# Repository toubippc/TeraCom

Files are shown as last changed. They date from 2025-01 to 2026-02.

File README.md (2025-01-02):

# Firware TeraCom esp32

Version beta : 0.2

## Description

Ce firware charger sur un esp32 permet le controle de températures, de l'éclairage et de la circulation d'air dans un terrarium.

Via un pin/switch on peu le passer en mode station ( hotspot ),de facon a se connecter directement a l'appareil ( il emet son propre signal wifi/ssid ) ou en mode client, en le connectant a son réseaux existant.
Vou devez pour se faire l'initialisé en vous connectant une première fois en mode station.

### 4 sorties relay

- Chauffage / Tapis de sol
- Lumière chauffante ( spot )
- Lumière spéciale ( UV )
- Ventilation / Humidificateur

### Sondes d'entrées

- 1 DHT 11 (température / Humidité )
- 3 Sondes de témperatures DS18B20

D'autre fonction avec de multiple sondes sont a venir ! 
(la liste est trop longue .. )

> [!IMPORTANT]
> Manuel d'utilisation a venir !

## Technique

### Hardware

- Carte : esp32doit-devkit-v1
- Shéma :
- Sondes compatibles :

### Software

Développé avec VSCode

platform = espressif32 \
board = esp32doit-devkit-v1 \
framework = arduino \
lib_deps =

    - ottowinter/ESPAsyncWebServer-esphome@^3.1.0
    - ottowinter/ESPAsyncTCP-esphome@^1.2.3
    - adafruit/Adafruit Unified Sensor@^1.1.14
    - adafruit/DHT sensor library@^1.4.6
    - paulstoffregen/OneWire@^2.3.8
    - milesburton/DallasTemperature@^3.11.0
    - ayushsharma82/AsyncElegantOTA@^2.2.8

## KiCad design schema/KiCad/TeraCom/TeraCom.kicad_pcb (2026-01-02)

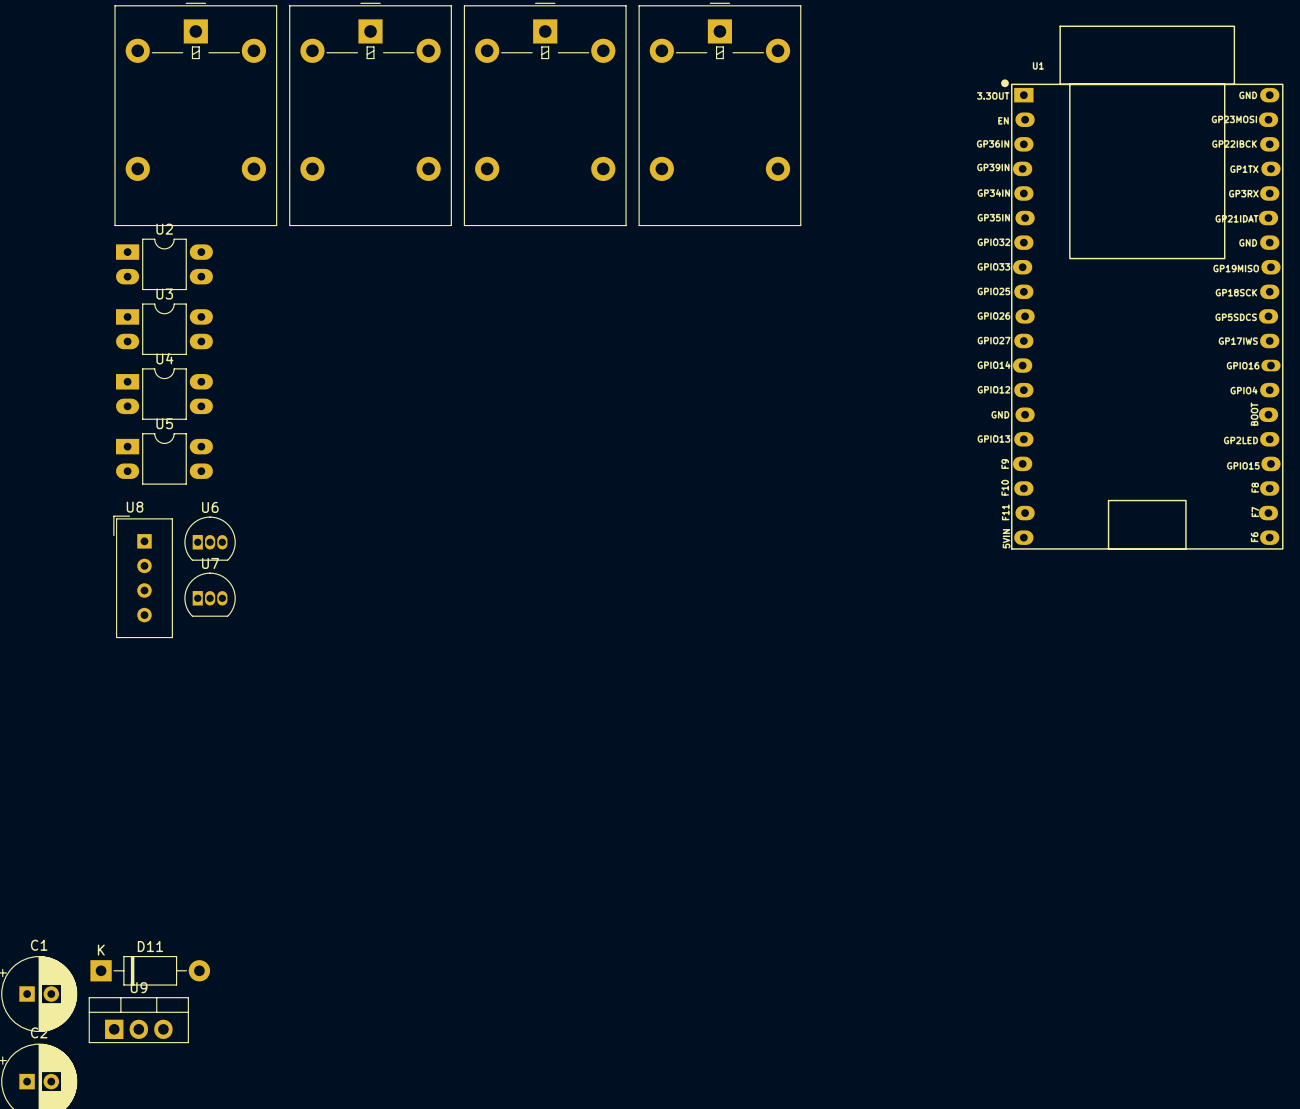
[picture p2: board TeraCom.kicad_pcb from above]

Board: 2 copper layers, 16 parts (0 on the bottom side), 14 nets, no tracks yet.

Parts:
C1, C2: C_Polarized_Small_US; CP_Radial_D7.5mm_P2.50mm
D11: 1N4007; D_DO-41_SOD81_P10.16mm_Horizontal
K1, K2, K3, K5: G5LE-1; Relay_SPDT_Omron-G5LE-1
U1: ESP32-C6-DevKitM-1; Z_ESP32_DevKitC_38pin_socket
U2, U3, U4, U5: PC817; DIP-4_W7.62mm_LongPads
U6, U7: DS18S20; TO-92_Inline
U8: DHT11; Aosong_DHT11_5.5x12.0_P2.54mm
U9: LM7805_TO220; TO-220-3_Vertical

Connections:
+5V: C2.1, U6.3 (V_{DD}), U7.3 (V_{DD}), U8.1 (VDD), U9.3 (VO)
GND_RELAY_CARD: C1.2, C2.2, U2.3, U3.3, U4.3, U5.3, U6.1 (GND), U7.1 (GND), U8.4 (GND), U9.2 (GND)
unnamed: K5.2, U2.4
unnamed: K1.2, U3.4
unnamed: K2.2, U4.4
unnamed: K3.2, U5.4
unnamed: U1.7 (GPIO0), U6.2 (DQ)
unnamed: U1.5 (GPIO4/MTMS), U7.2 (DQ)
unnamed: U1.32 (GPIO32), U8.2 (DATA)
unnamed: C1.1, U9.1 (VI)
POWER_RELAY_CARD: D11.2 (A), K1.5, K2.5, K3.5, K5.5
Relay_INPUT1: U1.28 (GPIO17/U0RXD), U2.2
Relay_INPUT2: U1.22 (GPIO18), U3.2
Relay_INPUT4: U1.29 (GPIO16/U0TXD), U5.2

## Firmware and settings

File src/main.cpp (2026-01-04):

#include "global.h"
#include "wifiSettings.h"
#include "server.h"
#include "wpse324.h"
#include "automation.h"



//UPDATE variabls to blink without delay:
const int led = 2;
unsigned long previousMillis = 0;        // will store last time LED was updated
const long interval = 1000;           // interval at which to blink (milliseconds)
int ledState = LOW;             // ledState used to set the LED


//Variables Server
String esid = "";
String epass = "";
int i = 0;
// Get Wifi mode trigger
int switchWifiMode = 3;

// NTP (time.h)
const char* ntpServer = "pool.ntp.org";
const long  gmtOffset_sec = 0;
const int   daylightOffset_sec = 0;

// SENSORS delay
uint32_t delayMS;

//Function Decalration
void launchWeb(void);
void setupAP(void);

void setup()
{

  Serial.begin(115200); //Initialising if(DEBUG)Serial Monitor
  Serial.println();
  Serial.println("Disconnecting current wifi connection");
  WiFi.disconnect();
  Serial.println("System Initializing ... ");

  pinMode(pinRelay0, OUTPUT);
  pinMode(pinRelay1, OUTPUT);
  pinMode(pinRelay2, OUTPUT);
  pinMode(pinRelay3, OUTPUT);
  pinMode(pinLedWifiAP, OUTPUT);
  pinMode(pinLedWifiSTA, OUTPUT);
  pinMode(pinTriggerAP, INPUT);

  //pinMode(analogIn1, INPUT);
  //pinMode(analogIn2, INPUT);
  //pinMode(analogIn3, INPUT);
  //pinMode(analogIn4, INPUT);

  digitalWrite(pinRelay0, OFF);
  digitalWrite(pinRelay1, OFF);
  digitalWrite(pinRelay2, OFF);
  digitalWrite(pinRelay3, OFF);
  digitalWrite(pinLedWifiAP, LOW);
  digitalWrite(pinLedWifiSTA, LOW);
  //digitalWrite(analogIn1, LOW);
  //digitalWrite(analogIn2, LOW);

  
  // configure LED PWM functionalitites
  ledcSetup(ledChannel, freq, resolution);
  
  // attach the channel to the GPIO to be controlled
  ledcAttachPin(output, ledChannel);
  
  // configure PWM frequency
  ledcWrite(ledChannel, sliderValue.toInt());

  //Initialasing EEPROM
  EEPROM.begin(512); 
  delay(10);
  

  //---------------------------------------- Read eeprom for ssid and pass
  Serial.println("Reading EEPROM ssid");
  for (int i = 0; i < 32; ++i)
  {
    esid += char(EEPROM.read(i));
  }
  Serial.println();
  Serial.print("SSID: ");
  Serial.println(esid);
  Serial.println("Reading EEPROM pass");

  for (int i = 32; i < 96; ++i)
  {
    epass += char(EEPROM.read(i));
  }
  Serial.print("PASS: ");
  Serial.println(epass);

  // Configure WiFi
  WiFi.mode(WIFI_STA);
  WiFi.config(INADDR_NONE, INADDR_NONE, INADDR_NONE, INADDR_NONE);
  WiFi.setHostname(hostname.c_str()); //define hostname
  WiFi.disconnect();
  delay(100);


  // END initialization, start loop
  Serial.println();
  Serial.println("Startup : ");
  Serial.println(hostname.c_str());
  
  // SENSORS
  
   dht.begin();
   wpse324init();
  Serial.println(F("DHTxx Unified Sensor Example"));
  // Print temperature sensor details.
  sensor_t sensor;
  dht.temperature().getSensor(&sensor);
  Serial.println(F("------------------------------------"));
  Serial.println(F("Temperature Sensor"));
  Serial.print  (F("Sensor Type: ")); Serial.println(sensor.name);
  Serial.print  (F("Driver Ver:  ")); Serial.println(sensor.version);
  Serial.print  (F("Unique ID:   ")); Serial.println(sensor.sensor_id);
  Serial.print  (F("Max Value:   ")); Serial.print(sensor.max_value); Serial.println(F("°C"));
  Serial.print  (F("Min Value:   ")); Serial.print(sensor.min_value); Serial.println(F("°C"));
  Serial.print  (F("Resolution:  ")); Serial.print(sensor.resolution); Serial.println(F("°C"));
  Serial.println(F("------------------------------------"));
  // Print humidity sensor details.
  dht.humidity().getSensor(&sensor);
  Serial.println(F("Humidity Sensor"));
  Serial.print  (F("Sensor Type: ")); Serial.println(sensor.name);
  Serial.print  (F("Driver Ver:  ")); Serial.println(sensor.version);
  Serial.print  (F("Unique ID:   ")); Serial.println(sensor.sensor_id);
  Serial.print  (F("Max Value:   ")); Serial.print(sensor.max_value); Serial.println(F("%"));
  Serial.print  (F("Min Value:   ")); Serial.print(sensor.min_value); Serial.println(F("%"));
  Serial.print  (F("Resolution:  ")); Serial.print(sensor.resolution); Serial.println(F("%"));
  Serial.println(F("------------------------------------"));
  // Set delay between sensor readings based on sensor details.
  delayMS = sensor.min_delay / 1000;
         
}


void loop() {

 // analog1Value = analogRead(analogIn1);
 // analog2Value = analogRead(analogIn2);
  // analog3Value = analogRead(analogIn3); // DHT11
  // analog4Value = analogRead(analogIn4);

  //String strAnalog1 = "Analogique 34 : "+analog1Value;
  //Serial.printf("Analogique 3 : %d \n",analog3Value);
  //Serial.printf("Analogique 4 : %d \n", analog4Value);

  // Get Wifi mode trigger
  // Pin trigger LOW && connection false
  if (digitalRead(pinTriggerAP) != 1 && switchWifiMode != digitalRead(pinTriggerAP)) {
    Serial.println(" Wifi station initialization ...");
    switchWifiMode = 0;
    setupSTA();
    if (WiFi.status() == WL_CONNECTED)
      {
          // Init and get the time
        configTime(gmtOffset_sec, daylightOffset_sec, ntpServer);
        setTimezone("CET-1CEST,M3.5.0,M10.5.0/3");
        launchWeb();
        // ElegantOTA.loop();
      }
  } 
  else if(digitalRead(pinTriggerAP) == 1 && switchWifiMode != digitalRead(pinTriggerAP)) {
    Serial.println(" Wifi access point initialization ...");
    setupAP();// Setup HotSpot
    switchWifiMode = 1;
  }
  else {
    // When no connection or lost connection
    if(WiFi.status() != WL_CONNECTED && switchWifiMode == 0 ) {
      // when the connection is lost
      if(WiFi.status() == WL_CONNECTION_LOST ) {
        Serial.println(" Lost connection, reconnect .. ");
        WiFi.reconnect();
      }
      // when disconnected from a network
      else if(WiFi.status() == WL_DISCONNECTED) {
        Serial.println(" Disconnected !");
        switchWifiMode = 1;
      }
      // when the connection fails for all the attempts
      else if(WiFi.status() == WL_CONNECT_FAILED) {
        Serial.println(" Connection failed, switch to Access Point mode !");
        switchWifiMode = 1;
      }
    }
    else if(WiFi.status() == WL_CONNECTED) {
        Serial.println("WiFi connected !");
        printLocalTime();
    }
      // Default
      // switchWifiMode = digitalRead(pinTriggerAP);
      String mode = (switchWifiMode == 1) ? "Access Point" : "Station";
      Serial.printf(" Wifi on : %s \n",mode.c_str());
      IPAddress ip = (switchWifiMode == 1) ? WiFi.softAPIP() : WiFi.localIP();
      String ipStr = String(ip[0]) + '.' + String(ip[1]) + '.' + String(ip[2]) + '.' + String(ip[3]);
      Serial.println(ipStr.c_str());
        // Delay between measurements.
        // delay(delayMS);
        // Get temperature event and print its value.
        
        dht.temperature().getEvent(&event);
        if (isnan(event.temperature)) {
          Serial.println(F("Error reading temperature!"));
        }
        else {
          Serial.print(F("Temperature: "));
          Serial.print(event.temperature);
          analog3Value = event.temperature;
          Serial.print(" \xC2\xB0"); // shows degree symbol
          Serial.println(F("C"));
        }
        // Get humidity event and print its value.
        dht.humidity().getEvent(&event);
        if (isnan(event.relative_humidity)) {
          Serial.println(F("Error reading humidity!"));
        }
        else {
          Serial.print(F("Humidity: "));
          Serial.print(event.relative_humidity);
          analog4Value = event.relative_humidity;
          Serial.println(F("%"));
        }
        wpse324();
        automation();
          

      delay(2000);
    
  }

}


void launchWeb()
{
  Serial.println("");
  if (WiFi.status() == WL_CONNECTED)
    Serial.println("WiFi connected");
  Serial.print("Local IP: ");
  Serial.println(WiFi.localIP());
  Serial.print("SoftAP IP: ");
  Serial.println(WiFi.softAPIP());
  // Start the server
  createWebServer();
  Serial.println("Server started");
}


void setupAP(void)
{
  scanWifi();
  WiFi.disconnect();
  delay(100);
  WiFi.softAP(WIFI_AP_Name.c_str(), "");
  Serial.println("Initializing_softap_for_wifi credentials_modification");
  launchWeb();
  digitalWrite(pinLedWifiSTA, LOW);
  digitalWrite(pinLedWifiAP, HIGH);
  Serial.println("over");
}



void printLocalTime(){
  if(!getLocalTime(&timeinfo)){
    Serial.println("Failed to obtain time");
    return;
  }
  Serial.println(&timeinfo, "%A, %B %d %Y %H:%M:%S");
  /*
  Serial.print("Day of week: ");
  Serial.println(&timeinfo, "%A");
  Serial.print("Month: ");
  Serial.println(&timeinfo, "%B");
  Serial.print("Day of Month: ");
  Serial.println(&timeinfo, "%d");
  Serial.print("Year: ");
  Serial.println(&timeinfo, "%Y");
  Serial.print("Hour: ");
  Serial.println(&timeinfo, "%H");
  Serial.print("Hour (12 hour format): ");
  Serial.println(&timeinfo, "%I");
  Serial.print("Minute: ");
  Serial.println(&timeinfo, "%M");
  Serial.print("Second: ");
  Serial.println(&timeinfo, "%S");

  Serial.println("Time variables");
  char timeHour[3];
  strftime(timeHour,3, "%H", &timeinfo);
  Serial.println(timeHour);
  char timeWeekDay[10];
  strftime(timeWeekDay,10, "%A", &timeinfo);
  Serial.println(timeWeekDay);
  Serial.println();
  */
}

void setTimezone(String timezone){
  Serial.printf("  Setting Timezone to %s\n",timezone.c_str());
  setenv("TZ",timezone.c_str(),1);  //  Now adjust the TZ.  Clock settings are adjusted to show the new local time
  tzset();
}

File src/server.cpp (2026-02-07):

#include "server.h"
#include "wifiSettings.h"
//#include <ElegantOTA.h>

#include "html/style.h"
#include "html/network_html.h"
#include "html/tweak_html.h"
// #include "dc_motors/move.h"
#include "html/update_html.h"
#include "html/index_html.h"
#include "html/program_html.h"
#include "html/settings_html.h"
#include "html/summer_scenario_html.h"
#include "html/winter_scenario_html.h"

// DEVAULT VALUE
String stateout0 = "OFF";
String stateout1 = "OFF";
String stateout2 = "OFF";
String stateout3 = "OFF";
String analog1 = "0";
String analog2 = "0";
String analog3 = "0";
String analog4 = "0";
String content;
int statusCode;

/*
unsigned long ota_progress_millis = 0;

void onOTAStart() {
  // Log when OTA has started
  Serial.println("OTA update started!");
  // <Add your own code here>
}

void onOTAProgress(size_t current, size_t final) {
  // Log every 1 second
  if (millis() - ota_progress_millis > 1000) {
    ota_progress_millis = millis();
    Serial.printf("OTA Progress Current: %u bytes, Final: %u bytes\n", current, final);
  }
}

void onOTAEnd(bool success) {
  // Log when OTA has finished
  if (success) {
    Serial.println("OTA update finished successfully!");
  } else {
    Serial.println("There was an error during OTA update!");
  }
  // <Add your own code here>
}
*/


// Replaces placeholder with button section in your web page
String processor(const String& var){
  //Serial.println(var);
  
  if (var == "SLIDERVALUE"){
    return sliderValue;
  } else {
    sliderValue = 128;
  }

  if(var == "RELAY0") {return NameRelay0; }
  if(var == "RELAY1") {return NameRelay1; }
  if(var == "RELAY2") {return NameRelay2; }
  if(var == "RELAY3") {return NameRelay3; }

  if(var == "SONDE1") {return NameSensors1; }
  if(var == "SONDE2") {return NameSensors2; }
  if(var == "SONDE3") {return NameSensors3; }
  if(var == "SONDE4") {return NameSensors4; }
  if(var == "MODE") {return Mode; }

  if(var == "STATEOUT0") {
    return stateout0  = ( digitalRead(pinRelay0) == OFF ) ? "OFF" : "ON";
  }
    if(var == "STATEOUT1") {
    return stateout1  = ( digitalRead(pinRelay1) == OFF ) ? "OFF" : "ON";
  }
    if(var == "STATEOUT2") {
    return stateout2  = ( digitalRead(pinRelay2) == OFF ) ? "OFF" : "ON";
  }
    if(var == "STATEOUT3") {
    return stateout3  = ( digitalRead(pinRelay3) == OFF ) ? "OFF" : "ON";
  }

  if(var == "ANALOG1") {
    analog1 = String(analog1Value);
    return analog1;
  }
  if(var == "ANALOG2") {
    analog2 = String(analog2Value);
    return analog2;
  }
  
  if(var == "ANALOG3") {
    analog3 = String(analog3Value);
    return analog1;
  }
  if(var == "ANALOG4") {
    analog4 = String(analog4Value);
    return analog1;
  }
  if(var == "DHT1") {
    
    return String(analog3Value);
  }
  if(var == "HUMIDITY") {
    return String(analog4Value);
  }
  if(var == "TIME") {
    String time = String(timeinfo.tm_hour)+":"+String(timeinfo.tm_min);
    return String(time);
  }
  if(var == "ECU") {
    String ecuState = (ECU_STATE == 0) ? "OFF" : "ON";
    return ecuState;
  }
  
  
  Serial.println(var);
  return String();
}

// Router URL AND GET PARAM
void createWebServer()
{
  {
    /*
    ElegantOTA.begin(&server);    // Start ElegantOTA
    // ElegantOTA callbacks
    ElegantOTA.onStart(onOTAStart);
    ElegantOTA.onProgress(onOTAProgress);
    ElegantOTA.onEnd(onOTAEnd);
    */
    server.begin();
    Serial.println("HTTP server started");
    ElegantOTA.begin(&server);    // Start ElegantOTA
    ElegantOTA.loop();
    
    NameRelay0 = (EEPROM.readString(64) == "") ? "Relay 0" : EEPROM.readString(64);
    NameRelay1 = (EEPROM.readString(128) == "") ? "Relay 1" : EEPROM.readString(128);
    NameRelay2 = (EEPROM.readString(196) == "") ? "Relay 2" : EEPROM.readString(196);
    NameRelay3 = (EEPROM.readString(256) == "") ? "Relay 3" : EEPROM.readString(256);
    
   server.on("/", HTTP_GET, [](AsyncWebServerRequest *request){
    request->send_P(200, "text/html", index_html, processor);
    });
    
    // return time
    server.on("/gettime", HTTP_GET, [](AsyncWebServerRequest *request){
      String timeString = String(timeinfo.tm_mon) + " " + String(timeinfo.tm_mday) + " " + String(timeinfo.tm_year) + " " + String(timeinfo.tm_hour) + ":" + String(timeinfo.tm_min) + ":" + String(timeinfo.tm_sec);
      char buff[70];
      strftime(buff, sizeof buff, " %B %d %Y %T ", &timeinfo);
      content = "{\"time\" : \""+ String(buff) +"\"}";
      statusCode = 200;
      request->send(statusCode, "application/json", content);
    });
    
    server.on("/getdht11", HTTP_GET, [](AsyncWebServerRequest *request){
      /* dht.temperature().getEvent(&event);
      String temperature = String(event.temperature);
      dht.humidity().getEvent(&event);
      String humitidty = String(event.relative_humidity); */
      content = "{\"temperature_0\" : "+String(analog1Value);
      content += ",\"temperature_1\" : "+String(analog2Value);
      content += +",\"dht_1\" : "+String(analog3Value);
      content += +", \"humidity_1\" : "+String(analog4Value);
      content += +", \"relay0\" : "+ String((digitalRead(pinRelay0) == OFF && RELAY_INV==1 ? "0" : "1"));
      content += +", \"relay1\" : "+ String((digitalRead(pinRelay1) == OFF && RELAY_INV==1 ? "0" : "1"));
      content += +", \"relay2\" : "+ String((digitalRead(pinRelay2) == OFF && RELAY_INV==1 ? "0" : "1"));
      content += +", \"relay3\" : "+ String((digitalRead(pinRelay3) == OFF && RELAY_INV==1 ? "0" : "1"));
      content += +"}";
      statusCode = 200;
      request->send(statusCode, "application/json", content);
    });

  // Send a GET request to <ESP_IP>/slider?value=<inputMessage>
  server.on("/slider", HTTP_GET, [] (AsyncWebServerRequest *request) {
    String inputMessage;
    // GET input1 value on <ESP_IP>/slider?value=<inputMessage>
    if (request->hasParam(PARAM_INPUT)) {
      inputMessage = request->getParam(PARAM_INPUT)->value();
      sliderValue = inputMessage;
      ledcWrite(ledChannel, sliderValue.toInt());
    }
    // GET input1 value on <ESP_IP>?temp=<inputMessage>
    else if(request->hasParam(HTTP_GET_PARAM)) {
      inputMessage = request->getParam(HTTP_GET_PARAM)->value();
      Relay0_status = inputMessage;
      // TODO : ON/OFF function here
     
      if (Relay0_status == "Fermer"){
         digitalWrite(pinRelay0, HIGH);
         digitalWrite(analogIn1, LOW);
         digitalWrite(analogIn2, HIGH);
         delay(timeMotor1);
      digitalWrite(analogIn1, LOW);
         digitalWrite(analogIn2, LOW);
         digitalWrite(pinRelay0, LOW);
      } else {
          digitalWrite(pinRelay0, HIGH);
          digitalWrite(analogIn2, LOW);
         digitalWrite(analogIn1, HIGH);
         delay(timeMotor1);
          digitalWrite(analogIn1, LOW);
         digitalWrite(analogIn2, LOW);
         digitalWrite(pinRelay0, LOW);
        }
    }
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

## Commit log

2025-01-02 Add second DS18B20 sensor on pin 4
2025-06-07 Bug fix & Gauge
    [automation.cpp, global.cpp, main.cpp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]
2025-10-27 Add Kicad Schematic
    [TeraCom.kicad_pcb, TeraCom.kicad_sch, relays.kicad_sch]
2026-01-02 Add setting and bugs corrections
    [automation.cpp, global.cpp, main.cpp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]
2026-01-02 Ajout du fichier idedata.json pour la configuration de l'environnement esp32doit-devkit-v1
2026-01-10 Update and fix interface
    [server.cpp]
2026-02-07 Update interface
    [TeraCom.kicad_pcb, TeraCom.kicad_sch, relays.kicad_sch]
